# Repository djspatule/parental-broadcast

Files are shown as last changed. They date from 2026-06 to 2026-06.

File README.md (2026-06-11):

# parental-broadcast

A one-button Wi-Fi intercom for children's bedrooms, built on an **ESP32** +
**MAX98357A** I2S amplifier. Open a web page on your phone, tap a button, and a
pre-recorded voice message plays through the speaker in the kids' room — no app,
no cloud, no subscription.

```
Phone (same Wi-Fi)
      |
      | HTTP  →  http://interphone-enfants.local
      |
   ESP32
      |
      | I2S (BCLK / LRC / DIN)
      |
  MAX98357A  →  Speaker (4 Ω or 8 Ω, 1–3 W)
```

---

## Hardware

### Required

| Part | Notes |
| --- | --- |
| ESP32 DevKit (or equivalent) | Any classic ESP32 with 4 MB flash |
| MAX98357A I2S amplifier module | Adafruit breakout or clone |
| Speaker, 4 Ω or 8 Ω, 1–3 W | Small bookshelf or project speaker |
| Dupont wires | |
| USB cable + stable USB power supply | Dedicated supply preferred over a laptop port |

### Recommended but not required for V1

- Small enclosure
- Status LED (see [Improvements](#improvements))
- Physical mute button (see [Improvements](#improvements))

---

## Wiring

| MAX98357A pin | ESP32 pin |
| --- | --- |
| VIN | 5 V |
| GND | GND |
| BCLK | GPIO 26 |
| LRC | GPIO 25 |
| DIN | GPIO 22 |
| SD | 3.3 V or VIN (must not float — LOW = shutdown) |

| Speaker terminal | MAX98357A terminal |
| --- | --- |
| + | OUT+ |
| − | OUT− |

> **Do not connect headphones** to the MAX98357A output — it is a speaker
> amplifier, not a headphone driver.

---

## Software setup

### Prerequisites

- [VS Code](https://code.visualstudio.com/) +
  [PlatformIO extension](https://platformio.org/install/ide?install=vscode)
- [ffmpeg](https://ffmpeg.org/) (for audio conversion)

### 1. Clone the repo

```bash
git clone https://github.com/YOUR_USERNAME/parental-broadcast.git
cd parental-broadcast
```

### 2. Set your Wi-Fi credentials

Edit `src/main.cpp`, lines near the top:

```cpp
const char* WIFI_SSID = "YOUR_WIFI_SSID";
const char* WIFI_PASS = "YOUR_WIFI_PASSWORD";
```

> Never commit real credentials. The `.gitignore` does not protect `main.cpp` —
> keep a local-only copy if needed.

### 3. Prepare audio files

Record your own voice for each message (your voice works better with children
than a robot). Suggested messages:

| Filename | Suggested phrase |
| --- | --- |
| `moins_fort.wav` | "Les enfants, moins fort s'il vous plaît." |
| `retour_lit.wav` | "Retournez au lit maintenant." |
| `stop_courir.wav` | "Arrêtez de courir, vous allez réveiller tout le monde." |
| `separez_vous.wav` | "Séparez-vous tout de suite." |
| `tout_va_bien.wav` | "Tout va bien ?" |
| `papa_arrive.wav` | "Je vous entends, calmez-vous." |
| `dernier_avertissement.wav` | "Dernier avertissement, sinon je viens." |

Convert to the required format (mono, 16-bit PCM, 16 kHz) using the provided
script:

```bash
# Convert all *.m4a files in the current directory, output to data/
./scripts/convert_audio.sh

# Or convert a single file
./scripts/convert_audio.sh recording.m4a

# Manual ffmpeg command
ffmpeg -i input.m4a -ac 1 -ar 16000 -sample_fmt s16 data/moins_fort.wav
```

**Required WAV spec:**

| Parameter | Value |
| --- | --- |
| Container | WAV |
| Encoding | PCM (uncompressed) |
| Channels | Mono (1) |
| Bit depth | 16-bit |
| Sample rate | 16 000 Hz (or 22 050 Hz) |

Approximate sizes: 1 s ≈ 32 KB · 5 s ≈ 160 KB · 10 messages × 3 s ≈ 960 KB —
fits easily in 4 MB flash with a LittleFS partition.

### 4. Flash the firmware

Plug in the ESP32, then from VS Code PlatformIO terminal (or a terminal in the
project root):

```bash
# Compile and upload the firmware
pio run --target upload

# Upload the audio files to LittleFS
pio run --target uploadfs

# Open the serial monitor
pio device monitor
```

Expected serial output on boot:

```
Starting children's intercom...
Files in LittleFS:
  - /moins_fort.wav (48234 bytes)
  - /retour_lit.wav (51890 bytes)
  ...
Connected. IP: 192.168.1.42
mDNS active: http://interphone-enfants.local
HTTP server started.
```

---

## Usage

From your phone (connected to the same Wi-Fi):

```
http://interphone-enfants.local
```

If mDNS does not resolve (some Android versions), use the IP shown in the serial
monitor:

```
http://192.168.1.42
```

You can also trigger playback directly:

```
http://192.168.1.42/play?msg=moins_fort
```

**Tip:** on iPhone or Android, add the page to the home screen — it will appear
as a pseudo-app icon.

---

## Project structure

```
parental-broadcast/
├── platformio.ini          # PlatformIO build config
├── src/
│   └── main.cpp            # All ESP32 firmware
├── data/                   # WAV files go here (not committed)
│   └── .gitkeep
└── scripts/
    └── convert_audio.sh    # ffmpeg batch converter
```

---

## Configuration reference

All tuneable constants are at the top of `src/main.cpp`:

| Constant | Default | Description |
| --- | --- | --- |
| `WIFI_SSID` | `"YOUR_WIFI_SSID"` | Your Wi-Fi network name |
| `WIFI_PASS` | `"YOUR_WIFI_PASSWORD"` | Your Wi-Fi password |
| `MDNS_NAME` | `"interphone-enfants"` | mDNS hostname (`<name>.local`) |
| `I2S_BCLK`  | `26` | ESP32 GPIO for I2S bit clock |
| `I2S_LRC` | `25` | ESP32 GPIO for I2S word select |
| `I2S_DOUT`  | `22` | ESP32 GPIO for I2S data |
| `VOLUME` | `0.45` | Software volume, `0.0`–`1.0` |

---

## Fixing the IP address

mDNS is convenient, but a reserved IP in your router is more reliable for direct
access and troubleshooting. Look for "DHCP reservation" or "static lease" in
your router admin panel and assign a fixed IP to the ESP32's MAC address
(printed on the serial monitor at boot, or via `WiFi.macAddress()`).

---

## Improvements

These are out of scope for V1 but easy to add later:

### Status LED

```cpp
#define LED_PIN 2
digitalWrite(LED_PIN, isPlaying ? HIGH : LOW);
```

Suggested behaviour: solid = connected, blinking = playing, fast blink = Wi-Fi
error.

### Physical mute button

Wire a momentary button between GPIO 32 and GND, configure `INPUT_PULLUP`, and
set a `muted` flag that `playWav()` checks.

### Admin endpoints

- `GET /status` — already implemented, returns JSON
- `GET /reboot` — calls `ESP.restart()`
- `GET /volume?value=0.3` — updates `VOLUME` at runtime

### Attention chime

Play a short `ding.wav` before every message so children know to listen.

### Optional token authentication

If you ever expose the ESP32 beyond your local network (not recommended), add a
token to the URL:

```
/play?token=YOUR_SECRET&msg=moins_fort
```

In `handlePlay()`:

```cpp
const char* API_TOKEN = "change-me";

if (!server.hasArg("token") || server.arg("token") != API_TOKEN) {
  server.send(403, "text/plain", "Forbidden");
  return;
}
```

And include the token in the JavaScript `fetch()` call.

---

## Troubleshooting

| Symptom | Check |
| --- | --- |
| Page does not open via `.local` | Try the raw IP — mDNS is a best-effort protocol on some Android versions  |
| No sound | VIN→5 V, GND→GND, BCLK→26, LRC→25, DIN→22, SD→HIGH, speaker connected |
| Sound too fast or too slow | WAV is not 16 kHz — re-convert with `ffmpeg -ar 16000` |
| Sound is distorted / clipping | Lower `VOLUME` (e.g. `0.25`) |
| Message is cut off | A second button press while playing is silently ignored (by design) |
| File not found at runtime | Re-run `pio run --target uploadfs` and check the serial monitor file list |

---

## Security notes

- Do not expose this device to the internet (no port forwarding).
- The whitelist in `safeMessageToPath()` ensures arbitrary file paths cannot be
  requested via the URL.
- Keep the device on your home or IoT Wi-Fi network only.
- Keep the volume at a reasonable level.

---

## License

MIT — do whatever you want with it.

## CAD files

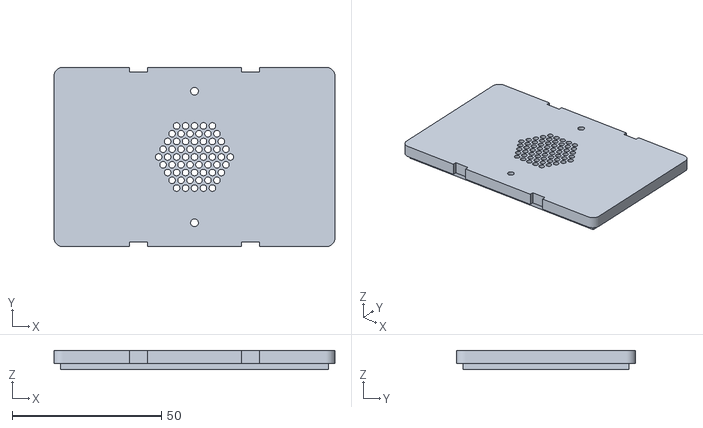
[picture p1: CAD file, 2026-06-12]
enclosure/interphone_lid.stl
94.0 x 60.0 x 6.50

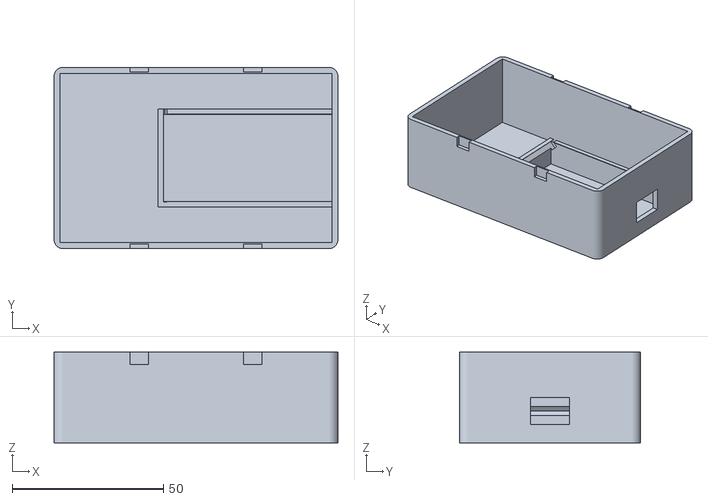
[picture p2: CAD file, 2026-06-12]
enclosure/interphone_body.stl
94.0 x 60.0 x 30.0

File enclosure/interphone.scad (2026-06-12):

// ============================================================
//  Children's Intercom — 3D-printable enclosure
//
//  Contents: ESP32 DevKit + MAX98357A + 31×31 mm top-firing
//            speaker (QUARKZMAN, JST-PH2.0, 2-ear, 44 mm span)
//
//  Two-part print — change PART then export each to STL:
//    PART = "body"   → the box (floor + walls + ESP32 cradle)
//    PART = "lid"    → the top plate with speaker grille
//    PART = "both"   → coloured preview in OpenSCAD viewer
//
//  Closure: 2 rubber bands running around the SHORT sides.
//  Notches on front + back long walls keep them from sliding up.
//
//  Hardware needed:
//    2 × M2.5×8 screws   (speaker ears → lid)
//    2 × rubber bands     (≈ 15–18 cm circumference)
// ============================================================

PART = "both"; // "body" | "lid" | "both"

// ── Shell ────────────────────────────────────────────────────
WALL  = 2.0;   // wall thickness everywhere
LID_T = 4.5;   // lid plate thickness
FIT   = 0.25;  // clearance between locating rim and body inner wall
LIP_H = 2.0;   // depth the locating rim descends into the body
LIP_W = 1.8;   // thickness of the hollow locating rim walls

// ── Internal cavity ─────────────────────────────────────────
// X = left–right (along ESP32 long axis, USB end toward right wall)
// Y = front–back
// Z = up (floor at z=WALL from outside bottom)
IN_W = 90;   // inner width  — 55 mm ESP32 + cradle wall + amp + wires
IN_D = 56;   // inner depth  — 28 mm ESP32 + clearance, centred
IN_H = 28;   // inner height — 8 mm under-PCB + PCB + headroom

// ── ESP32 cradle ─────────────────────────────────────────────
// U-channel (3 walls), open on the RIGHT (USB) end.
// The ESP32 drops in from above; the lid holds it down.
// USB cable exits straight through the right short wall.
//
// Measured ESP32 DevKit: 55 × 28 mm PCB, 8 mm of components below.
ESP_L   = 55;    // board length (X axis)
ESP_D   = 28;    // board width  (Y axis)
ESP_CLR =  0.4;  // clearance each side (total 0.8 mm — snug but insertable)
CRD_T   =  1.8;  // cradle wall thickness
CRD_H   = 10;    // cradle wall height (clips past PCB level at 8 mm)

// ── USB cable cutout (RIGHT short wall, x = OUT_W face) ──────
// ESP32 USB port sits at PCB height = WALL + 8 mm from box bottom.
// Hole is centred on that wall in Y, generous in Z.
USB_W   = 13;    // hole width  (micro-USB body ≈ 8 mm, cable ≈ 10 mm)
USB_H   =  9;    // hole height
USB_Z   =  6;    // bottom of hole from outside box bottom
                 // (PCB at 10 mm, USB connector ~1 mm below PCB top → 9 mm centre)

// ── Speaker (lid) ────────────────────────────────────────────
SPK_SPAN  = 44;   // ear screw hole span (Y axis), 2 holes
SPK_SCR_R =  1.3; // M2.5 self-tap radius in lid

GRL_R     = 13.0; // grille area radius
GRL_HOLE  =  1.1; // individual grille hole radius
GRL_PITCH =  3.0; // hex grid pitch

// ── Rubber-band notches (front + back long walls) ────────────
NOTCH_W = 6;    // notch width  (band sits in here)
NOTCH_H = 4;    // notch height from top of body wall downward
NOTCH_D = 1.5;  // notch depth  from outer surface inward

// ── Foot pads ────────────────────────────────────────────────
FOOT_R  = 4.0;
FOOT_H  = 0.8;
FOOT_IN = 7.0;

// ============================================================
//  Derived
// ============================================================
OUT_W  = IN_W + 2*WALL;   // outer width
OUT_D  = IN_D + 2*WALL;   // outer depth
BODY_H = IN_H + WALL;     // outer body height (floor + walls, open top)

$fn = 64;

LID_CX = OUT_W / 2;
LID_CY = OUT_D / 2;

// Cradle inner dimensions (with clearance)
CRD_IW = ESP_L + ESP_CLR * 2;  // inner length (X)
CRD_ID = ESP_D + ESP_CLR * 2;  // inner width  (Y)

// Cradle outer dimensions
CRD_OW = CRD_IW + CRD_T;       // +1 wall on closed (left) end only
CRD_OD = CRD_ID + CRD_T * 2;   // +1 wall each side (Y)

// Cradle position in box interior coordinates (before WALL offset)
// Right end of cradle flush with inner face of right wall
CRD_X = IN_W - CRD_OW;         // closed end x (inner coords)
CRD_Y = (IN_D - CRD_OD) / 2;   // centred in Y

// ============================================================
//  Helper — rounded rectangular prism
// ============================================================
module rbox(w, d, h, r = 3) {
    hull()
        for (x = [r, w-r], y = [r, d-r])
            translate([x, y, 0])
                cylinder(r=r, h=h);
}

// ============================================================
//  ESP32 CRADLE
//  Origin at the closed (left) end, floor level.
//  U-channel open toward +X (USB / right wall).
// ============================================================
module esp32_cradle() {
    // Lead-in chamfer height at top of walls for easier insertion
    CHAMFER = 1.5;

    difference() {
        // Outer block
        cube([CRD_OW, CRD_OD, CRD_H]);

        // Hollow centre (ESP32 slot), open on +X face
        translate([CRD_T, CRD_T, -0.1])
            cube([CRD_IW + 0.1, CRD_ID, CRD_H + 0.2]);

        // Chamfer the top inner edges of the two side walls for easy drop-in
        translate([CRD_T, CRD_T - 0.1, CRD_H - CHAMFER])
            rotate([-45, 0, 0])
                cube([CRD_IW, CHAMFER * 2, CHAMFER * 2]);
        translate([CRD_T, CRD_T + CRD_ID - CHAMFER + 0.1, CRD_H - CHAMFER])
            rotate([45, 0, 0])
                cube([CRD_IW, CHAMFER * 2, CHAMFER * 2]);

        // Chamfer the top inner edge of the closed end wall
        translate([CRD_T - CHAMFER, CRD_T - 0.1, CRD_H - CHAMFER])
            rotate([0, 45, 0])
                cube([CHAMFER * 2, CRD_OD + 0.2, CHAMFER * 2]);
    }
}

// ============================================================
//  BODY
// ============================================================
module body() {
    difference() {
        rbox(OUT_W, OUT_D, BODY_H);

        // Inner cavity (open top)
        translate([WALL, WALL, WALL])
            cube([IN_W, IN_D, IN_H + 1]);

        // USB hole — right short wall (x = OUT_W face), centred in Y
        translate([OUT_W - WALL - 0.1, OUT_D/2 - USB_W/2, USB_Z])
            cube([WALL + 0.2, USB_W, USB_H]);

        // Rubber-band notches — front long wall (y = 0 face)
        for (x = [OUT_W*0.3, OUT_W*0.7])
            translate([x - NOTCH_W/2, -0.1, BODY_H - NOTCH_H])
                cube([NOTCH_W, NOTCH_D + 0.1, NOTCH_H + 0.1]);

        // Rubber-band notches — back long wall (y = OUT_D face)
        for (x = [OUT_W*0.3, OUT_W*0.7])
            translate([x - NOTCH_W/2, OUT_D - NOTCH_D, BODY_H - NOTCH_H])
                cube([NOTCH_W, NOTCH_D + 0.1, NOTCH_H + 0.1]);
    }

    // ESP32 cradle — sits on interior floor, USB end toward right wall
    translate([WALL + CRD_X, WALL + CRD_Y, WALL])
        esp32_cradle();

    // Foot pads
    for (x = [FOOT_IN, OUT_W - FOOT_IN], y = [FOOT_IN, OUT_D - FOOT_IN])
        translate([x, y, 0])
            cylinder(r=FOOT_R, h=FOOT_H);
}

// ============================================================
//  LID  (print grille-face-up for cleanest holes)
// ============================================================
module lid() {
    RIM_OX = WALL + FIT;
    RIM_OY = WALL + FIT;
    RIM_OW = IN_W - 2*FIT;
    RIM_OD = IN_D - 2*FIT;
    RIM_IW = RIM_OW - 2*LIP_W;
    RIM_ID = RIM_OD - 2*LIP_W;

    difference() {
        union() {
            rbox(OUT_W, OUT_D, LID_T);

            // Locating rim — hollow square tube, hangs below plate
            translate([RIM_OX, RIM_OY, -LIP_H])
                difference() {
                    cube([RIM_OW, RIM_OD, LIP_H]);
                    translate([LIP_W, LIP_W, -0.1])
                        cube([RIM_IW, RIM_ID, LIP_H + 0.2]);
                }
        }

        // Speaker grille — hex grid, circular boundary, through full plate
        translate([LID_CX, LID_CY, -0.1])
            for (row = [-12:12], col = [-12:12]) {
                gx = col * GRL_PITCH + (abs(row) % 2) * GRL_PITCH / 2;
                gy = row * GRL_PITCH * 0.866;
                if (sqrt(gx*gx + gy*gy) < GRL_R)
                    translate([gx, gy, 0])
                        cylinder(r=GRL_HOLE, h=LID_T + 0.2);
            }

        // Speaker mounting holes — through plate AND rim where rim exists
        for (dy = [-1, 1])
            translate([LID_CX, LID_CY + dy * SPK_SPAN/2, -(LIP_H + 0.1)])
                cylinder(r=SPK_SCR_R, h=LID_T + LIP_H + 0.2);

        // Rubber-band notches on lid edges (same X positions as body notches)
        for (x = [OUT_W*0.3, OUT_W*0.7]) {
            translate([x - NOTCH_W/2, -0.1, -0.1])
                cube([NOTCH_W, NOTCH_D + 0.1, LID_T + 0.2]);
            translate([x - NOTCH_W/2, OUT_D - NOTCH_D, -0.1])
                cube([NOTCH_W, NOTCH_D + 0.1, LID_T + 0.2]);
        }
    }
}
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

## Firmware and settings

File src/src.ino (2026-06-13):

#include <Arduino.h>
#include <WiFi.h>
#include <WebServer.h>
#include <ESPmDNS.h>
#include <LittleFS.h>
#include "driver/i2s.h"
#include <time.h>
#include <math.h>

// Forward-declared here so arduino-cli prototype injection finds it before use
struct WavInfo {
  uint16_t audioFormat, numChannels, bitsPerSample;
  uint32_t sampleRate, dataStart, dataSize;
};

// =========================
// CONFIGURATION
// =========================

const char* WIFI_SSID = "YOUR_WIFI_SSID";
const char* WIFI_PASS = "YOUR_WIFI_PASSWORD";
const char* MDNS_NAME = "interphone-enfants";

#define I2S_PORT I2S_NUM_0
#define I2S_BCLK 26
#define I2S_LRC  25
#define I2S_DOUT 22

float VOLUME = 0.45;

// =========================
// GLOBALS
// =========================

WebServer server(80);
bool isPlaying = false;

#define LOG_FILE    "/playlog.txt"
#define LABELS_FILE "/labels.txt"

// Default labels — seeded into LABELS_FILE on first boot.
// Format: filename_stem=Display label[|css_class]
// css classes: (none)=blue, secondary=grey, warning=red
const char* DEFAULT_LABELS =
  "moins_fort=Moins fort\n"
  "retour_lit=Retour au lit\n"
  "stop_courir=Arrêtez de courir\n"
  "separez_vous=Séparez-vous\n"
  "tout_va_bien=Tout va bien|secondary\n"
  "papa_arrive=Parents arrivent mécontents|secondary\n"
  "dernier_avertissement=Dernier avertissement|warning\n";

// =========================
// LABELS (labels.txt)
// =========================

struct LabelEntry {
  String stem;   // filename without .wav
  String label;  // display text
  String cls;    // css class
};

static LabelEntry g_labels[32];
static int        g_labelCount = 0;

void loadLabels() {
  g_labelCount = 0;
  File f = LittleFS.open(LABELS_FILE, "r");
  if (!f) return;
  while (f.available() && g_labelCount < 32) {
    String line = f.readStringUntil('\n');
    line.trim();
    if (line.length() == 0) continue;
    int eq = line.indexOf('=');
    if (eq < 1) continue;
    String stem = line.substring(0, eq);
    String rest = line.substring(eq + 1);
    String lbl, cls;
    int pipe = rest.indexOf('|');
    if (pipe >= 0) { lbl = rest.substring(0, pipe); cls = rest.substring(pipe + 1); }
    else           { lbl = rest; cls = ""; }
    g_labels[g_labelCount++] = {stem, lbl, cls};
  }
  f.close();
}

void saveLabels() {
  File f = LittleFS.open(LABELS_FILE, "w");
  if (!f) return;
  for (int i = 0; i < g_labelCount; i++) {
    f.print(g_labels[i].stem + "=" + g_labels[i].label);
    if (g_labels[i].cls.length()) f.print("|" + g_labels[i].cls);
    f.print("\n");
  }
  f.close();
}

// Returns index of stem in g_labels, or -1
int findLabel(const String& stem) {
  for (int i = 0; i < g_labelCount; i++)
    if (g_labels[i].stem == stem) return i;
  return -1;
}

String getLabelFor(const String& stem) {
  int i = findLabel(stem);
  return i >= 0 ? g_labels[i].label : stem;
}

void addLabel(const String& stem, const String& label) {
  int i = findLabel(stem);
  if (i >= 0) { g_labels[i].label = label; }
  else if (g_labelCount < 32) { g_labels[g_labelCount++] = {stem, label, ""}; }
  saveLabels();
}

void removeLabel(const String& stem) {
  int i = findLabel(stem);
  if (i < 0) return;
  for (int j = i; j < g_labelCount - 1; j++) g_labels[j] = g_labels[j + 1];
  g_labelCount--;
  saveLabels();
}

// =========================
// LOG (playlog.txt)
// =========================
// Line format: "YYYY-MM-DD total stem1:n1,stem2:n2\n"

String getToday() {
  struct tm t;
  if (!getLocalTime(&t)) return "unknown";
  char buf[11];
  strftime(buf, sizeof(buf), "%Y-%m-%d", &t);
  return String(buf);
}

void incrementLog(const String& stem) {
  String today = getToday();
  if (today == "unknown") return;

  String content = "";
  File f = LittleFS.open(LOG_FILE, "r");
  if (f) { content = f.readString(); f.close(); }

  bool found = false;
  String output = "";
  int start = 0;

  while (start < (int)content.length()) {
    int nl = content.indexOf('\n', start);
    if (nl < 0) nl = content.length();
    String line = content.substring(start, nl);
    line.trim();
    start = nl + 1;
    if (line.length() == 0) continue;

    // Parse: date total detail
    int s1 = line.indexOf(' ');
    if (s1 < 0) { output += line + "\n"; continue; }
    String date = line.substring(0, s1);
    int s2 = line.indexOf(' ', s1 + 1);
    int total = 0;
    String detail = "";
    if (s2 < 0) { total = line.substring(s1 + 1).toInt(); }
    else        { total = line.substring(s1 + 1, s2).toInt(); detail = line.substring(s2 + 1); }

    if (date == today) {
      found = true;
      total++;
      // Update or add this stem in detail
      bool stemFound = false;
      String newDetail = "";
      int ds = 0;
      while (ds < (int)detail.length()) {
        int dc = detail.indexOf(',', ds);
        if (dc < 0) dc = detail.length();
        String pair = detail.substring(ds, dc);
        ds = dc + 1;
        if (pair.length() == 0) continue;
        int col = pair.indexOf(':');
        if (col < 0) { newDetail += (newDetail.length() ? "," : "") + pair; continue; }
        String pStem = pair.substring(0, col);
        int pCount   = pair.substring(col + 1).toInt();
        if (pStem == stem) { pCount++; stemFound = true; }
        newDetail += (newDetail.length() ? "," : "") + pStem + ":" + String(pCount);
      }
      if (!stemFound) newDetail += (newDetail.length() ? "," : "") + stem + ":1";
      output += date + " " + String(total) + " " + newDetail + "\n";
    } else {
      output += line + "\n";
    }
  }

  if (!found) output += today + " 1 " + stem + ":1\n";

  File fw = LittleFS.open(LOG_FILE, "w");
  if (fw) { fw.print(output); fw.close(); }
}

// =========================
// I2S SETUP
// =========================

void setupI2S(int sampleRate) {
  i2s_driver_uninstall(I2S_PORT);
  i2s_config_t cfg = {
    .mode = (i2s_mode_t)(I2S_MODE_MASTER | I2S_MODE_TX),
    .sample_rate = (uint32_t)sampleRate,
    .bits_per_sample = I2S_BITS_PER_SAMPLE_16BIT,
    .channel_format = I2S_CHANNEL_FMT_RIGHT_LEFT,
    .communication_format = I2S_COMM_FORMAT_STAND_I2S,
    .intr_alloc_flags = ESP_INTR_FLAG_LEVEL1,
    .dma_buf_count = 8,
    .dma_buf_len = 512,
    .use_apll = false,
    .tx_desc_auto_clear = true,
    .fixed_mclk = 0
  };
  i2s_pin_config_t pins = {
    .bck_io_num = I2S_BCLK,
    .ws_io_num  = I2S_LRC,
    .data_out_num = I2S_DOUT,
    .data_in_num  = I2S_PIN_NO_CHANGE
  };
  if (i2s_driver_install(I2S_PORT, &cfg, 0, NULL) != ESP_OK) return;
  i2s_set_pin(I2S_PORT, &pins);
  i2s_zero_dma_buffer(I2S_PORT);
}

// =========================
// CHIME (synthesised — no WAV file needed)
// =========================

void playChime() {
  const int SR = 16000;
  // Two tones: 880 Hz then 660 Hz, 180 ms each, with fade envelope
  float freqs[2] = {880.0f, 660.0f};
  const int TONE_SAMPLES = SR * 180 / 1000;   // 2880 samples per tone
  const int FADE         = SR * 30  / 1000;   // 30 ms fade in/out
  const int GAP          = SR * 40  / 1000;   // 40 ms silence between tones

  int16_t buf[128]; // stereo: 64 frames × 2 ch

  for (int t = 0; t < 2; t++) {
    float freq = freqs[t];
    int s = 0;
    while (s < TONE_SAMPLES) {
      int batch = min(64, TONE_SAMPLES - s);
      for (int i = 0; i < batch; i++) {
        int pos = s + i;
        float env = 1.0f;
        if (pos < FADE)                        env = (float)pos / FADE;
        else if (pos > TONE_SAMPLES - FADE)    env = (float)(TONE_SAMPLES - pos) / FADE;
        float v = sinf(2.0f * M_PI * freq * pos / SR) * env * VOLUME * 0.55f;
        int16_t sample = (int16_t)(v * 32767.0f);
        buf[i * 2]     = sample;
        buf[i * 2 + 1] = sample;
      }
      size_t written;
      i2s_write(I2S_PORT, buf, batch * 4, &written, portMAX_DELAY);
      s += batch;
    }
    // Gap
    memset(buf, 0, sizeof(buf));
    for (int g = 0; g < GAP; g += 64) {
      int batch = min(64, GAP - g);
      size_t written;
      i2s_write(I2S_PORT, buf, batch * 4, &written, portMAX_DELAY);
    }
  }
}

// =========================
// WAV PLAYER
// =========================

static bool readBytes(File& f, void* b, size_t n) { return f.read((uint8_t*)b, n) == n; }

static uint32_t readU32(File& f) {
  uint8_t b[4]; if (!readBytes(f, b, 4)) return 0;
  return b[0] | (b[1]<<8) | (b[2]<<16) | (b[3]<<24);
}
static uint16_t readU16(File& f) {
  uint8_t b[2]; if (!readBytes(f, b, 2)) return 0;
  return b[0] | (b[1]<<8);
}

bool parseWav(File& f, WavInfo& info) {
  char riff[4], wave[4];
  f.seek(0);
  if (!readBytes(f, riff, 4)) return false;
  readU32(f); // riff size
  if (!readBytes(f, wave, 4)) return false;
  if (strncmp(riff, "RIFF", 4) || strncmp(wave, "WAVE", 4)) return false;

  bool gotFmt = false, gotData = false;
  while (f.available()) {
    char id[4]; if (!readBytes(f, id, 4)) break;
    uint32_t sz = readU32(f);
    uint32_t pos = f.position();
    if (!strncmp(id, "fmt ", 4)) {
      info.audioFormat  = readU16(f);
      info.numChannels  = readU16(f);
      info.sampleRate   = readU32(f);
      readU32(f); readU16(f); // byteRate, blockAlign
      info.bitsPerSample = readU16(f);
      gotFmt = true;
    } else if (!strncmp(id, "data", 4)) {
      info.dataStart = pos;
      info.dataSize  = sz;
      gotData = true;
    }
    f.seek(pos + sz);
    if (gotFmt && gotData) break;
  }
  return gotFmt && gotData;
}

int16_t applyVolume(int16_t s) {
  int32_t v = (int32_t)(s * VOLUME);
  if (v >  32767) v =  32767;
  if (v < -32768) v = -32768;
  return (int16_t)v;
}

bool playWav(const char* path) {
  if (isPlaying) return false;
  isPlaying = true;

  File f = LittleFS.open(path, "r");
  if (!f) { Serial.printf("File not found: %s\n", path); isPlaying = false; return false; }

  WavInfo wav;
  if (!parseWav(f, wav) || wav.audioFormat != 1 || wav.bitsPerSample != 16) {
    Serial.println("Unsupported WAV format.");
    f.close(); isPlaying = false; return false;
  }

  Serial.printf("Playing: %s (%lu Hz, %u ch)\n", path, wav.sampleRate, wav.numChannels);
  setupI2S(wav.sampleRate);
  f.seek(wav.dataStart);

  uint8_t inBuf[512];
  int16_t outBuf[512];
  uint32_t remaining = wav.dataSize;

  while (remaining > 0) {
    size_t toRead = remaining > 512 ? 512 : remaining;
    size_t got    = f.read(inBuf, toRead);
    if (got == 0) break;
    remaining -= got;

    size_t written;
    if (wav.numChannels == 1) {
      size_t samples = got / 2, out = 0;
      for (size_t i = 0; i < samples; i++) {
        int16_t s = applyVolume(((int16_t*)inBuf)[i]);
        outBuf[out++] = s; outBuf[out++] = s;
        if (out >= 512) { i2s_write(I2S_PORT, outBuf, out*2, &written, portMAX_DELAY); out = 0; }
      }
      if (out) i2s_write(I2S_PORT, outBuf, out*2, &written, portMAX_DELAY);
    } else {
      int16_t* s16 = (int16_t*)inBuf;
      for (size_t i = 0; i < got/2; i++) s16[i] = applyVolume(s16[i]);
      i2s_write(I2S_PORT, inBuf, got, &written, portMAX_DELAY);
    }
    yield();
  }

  i2s_zero_dma_buffer(I2S_PORT);
  f.close();
  isPlaying = false;
  return true;
}

// =========================
// SECURITY
// =========================

bool isSafeStem(const String& stem) {
  if (stem.length() == 0 || stem.length() > 40) return false;
  for (int i = 0; i < (int)stem.length(); i++) {
    char c = stem[i];
    if (!isalnum(c) && c != '_' && c != '-') return false;
  }
  return true;
}

// =========================
// HTML — MAIN PAGE (dynamic)
// =========================

String htmlPage() {
  String html = F("<!doctype html><html lang='fr'><head>"
    "<meta charset='utf-8'><title>Interphone enfants</title>"
    "<meta name='viewport' content='width=device-width,initial-scale=1'><link rel='icon' href='/favicon.ico'>"
    "<style>"
    ":root{font-family:system-ui,-apple-system,sans-serif}"
    "body{margin:0;background:#111;color:#f5f5f5}"
    "main{max-width:520px;margin:0 auto;padding:20px}"
    "h1{font-size:1.8rem;margin-bottom:.3rem}"
    "p{color:#bbb;margin-top:0;margin-bottom:1.5rem}"
    "button{width:100%;border:0;border-radius:14px;padding:18px 16px;margin:8px 0;"
           "font-size:1.2rem;font-weight:650;background:#2f80ed;color:#fff;"
           "box-shadow:0 4px 12px rgba(0,0,0,.25);cursor:pointer}"
    "button:active{transform:scale(.98);background:#1c65c9}"
    ".secondary{background:#444}"
    ".warning{background:#b84040}"
    ".volume-row{display:flex;align-items:center;gap:12px;margin:20px 0 8px}"
    ".volume-row label{white-space:nowrap;color:#bbb;font-size:.95rem;min-width:90px}"
    "input[type=range]{flex:1;accent-color:#2f80ed}"
    "#vol-val{color:#f5f5f5;min-width:36px;text-align:right;font-size:.95rem}"
    "#status{margin-top:16px;padding:12px;background:#222;border-radius:10px;color:#ddd;min-height:1.2rem}"
    ".footer-links{display:flex;gap:20px;justify-content:center;margin-top:20px}"
    ".footer-links a{color:#888;font-size:.9rem;text-decoration:none}"
    ".footer-links a:hover{color:#bbb}"
    "</style></head><body><main>"
    "<h1>Chambre enfants</h1>"
    "<p>Appuie sur un bouton pour diffuser un message.</p>");

  for (int i = 0; i < g_labelCount; i++) {
    String path = "/" + g_labels[i].stem + ".wav";
    if (!LittleFS.exists(path)) continue;
    String cls = g_labels[i].cls.length() ? " class='" + g_labels[i].cls + "'" : "";
    html += "<button" + cls + " onclick=\"play('" + g_labels[i].stem + "')\">"
          + g_labels[i].label + "</button>\n";
  }

  html += F("<div class='volume-row'>"
    "<label for='vol'>Volume&nbsp;:</label>"
    "<input type='range' id='vol' min='0' max='3' step='0.05' value='0.45'"
    " oninput='updateVolDisplay(this.value)' onchange='setVolume(this.value)'>"
    "<span id='vol-val'>0.45</span></div>"
    "<div id='status'>Prêt.</div>"
    "<div class='footer-links'>"
    "<a href='/log'>📋 Journal</a>"
    "<a href='/manage'>⚙️ Gérer les messages</a>"
    "</div>"
    "</main><script>"
    "async function play(msg){"
      "const s=document.getElementById('status');"
      "s.textContent='Envoi : '+msg+'...';"
      "try{"
        "const r=await fetch('/play?msg='+encodeURIComponent(msg));"
        "s.textContent=r.ok?'Message envoyé.':'Erreur : '+(await r.text());"
      "}catch(e){s.textContent='Impossible de joindre l\\'ESP32.';}"
    "}"
    "function updateVolDisplay(v){document.getElementById('vol-val').textContent=parseFloat(v).toFixed(2);}"
    "async function setVolume(v){updateVolDisplay(v);await fetch('/volume?value='+v);}"
    "fetch('/status').then(r=>r.json()).then(d=>{"
      "if(d.volume!==undefined){document.getElementById('vol').value=d.volume;updateVolDisplay(d.volume);}"
    "}).catch(()=>{});"
    "</script></body></html>");

  return html;
}

// =========================
// HTML — LOG PAGE
// =========================

String htmlLog() {
  String html = F("<!doctype html><html lang='fr'><head>"
    "<meta charset='utf-8'><title>Journal</title>"
    "<meta name='viewport' content='width=device-width,initial-scale=1'><link rel='icon' href='/favicon.ico'>"
    "<style>"
    "body{font-family:system-ui,sans-serif;background:#111;color:#f5f5f5;margin:0;padding:20px}"
    "h1{font-size:1.5rem}a{color:#2f80ed}"
    "table{border-collapse:collapse;width:100%;max-width:600px;margin-top:16px}"
    "th,td{padding:10px 14px;text-align:left;border-bottom:1px solid #333;vertical-align:top}"
    "th{color:#bbb;font-weight:500}"
    ".total{font-weight:bold;white-space:nowrap}"
    ".detail{color:#bbb;font-size:.9rem;line-height:1.6}"
    "</style></head><body>"
    "<h1>Journal des messages</h1>"
    "<p><a href='/'>← Retour</a></p>");

  File f = LittleFS.open(LOG_FILE, "r");
  if (!f || f.size() == 0) {
    html += "<p style='color:#bbb'>Aucun message envoyé pour l'instant.</p>";
    if (f) f.close();
    html += "</body></html>";
    return html;
  }

  // Collect lines
  String lines[64]; int count = 0;
  while (f.available() && count < 64) {
    String line = f.readStringUntil('\n'); line.trim();
    if (line.length()) lines[count++] = line;
  }
  f.close();

  html += "<table><tr><th>Date</th><th>Total</th><th>Détail</th></tr>";
  for (int i = count - 1; i >= 0; i--) {
    int s1 = lines[i].indexOf(' ');
    if (s1 < 0) continue;
    int s2 = lines[i].indexOf(' ', s1 + 1);
    String date   = lines[i].substring(0, s1);
    String total  = s2 < 0 ? lines[i].substring(s1 + 1) : lines[i].substring(s1 + 1, s2);
    String detail = s2 < 0 ? "" : lines[i].substring(s2 + 1);

    // Build friendly detail string
    String friendlyDetail = "";
    int ds = 0;
    while (ds < (int)detail.length()) {
      int dc = detail.indexOf(',', ds);
      if (dc < 0) dc = detail.length();
      String pair = detail.substring(ds, dc); ds = dc + 1;
      int col = pair.indexOf(':');
      if (col < 0) continue;
      String stem = pair.substring(0, col);
      String cnt  = pair.substring(col + 1);
      if (friendlyDetail.length()) friendlyDetail += "<br>";
      friendlyDetail += getLabelFor(stem) + " &times;" + cnt;
    }

    html += "<tr><td>" + date + "</td><td class='total'>" + total
          + "</td><td class='detail'>" + (friendlyDetail.length() ? friendlyDetail : "-")
          + "</td></tr>";
  }
  html += "</table></body></html>";
  return html;
}

// =========================
// HTML — MANAGE PAGE
// =========================

String htmlManage() {
  size_t used  = LittleFS.usedBytes();
  size_t total = LittleFS.totalBytes();
  size_t free  = total - used;

  String html = F("<!doctype html><html lang='fr'><head>"
    "<meta charset='utf-8'><title>Gérer les messages</title>"
    "<meta name='viewport' content='width=device-width,initial-scale=1'><link rel='icon' href='/favicon.ico'>"
    "<style>"
    "body{font-family:system-ui,sans-serif;background:#111;color:#f5f5f5;margin:0;padding:20px}"
    "h1,h2{font-size:1.3rem}a{color:#2f80ed}"
    "table{border-collapse:collapse;width:100%;max-width:520px;margin:12px 0}"
    "th,td{padding:9px 12px;text-align:left;border-bottom:1px solid #333}"
    "th{color:#bbb;font-weight:500}"
    ".del{color:#e05;font-size:.85rem;text-decoration:none}"
    ".del:hover{text-decoration:underline}"
    "form{max-width:520px;margin-top:20px}"
    "label{display:block;color:#bbb;font-size:.9rem;margin:12px 0 4px}"
    "input[type=text],input[type=file]{width:100%;box-sizing:border-box;"
      "background:#222;border:1px solid #444;border-radius:8px;"
      "padding:10px;color:#f5f5f5;font-size:1rem}"
    "button[type=submit]{margin-top:14px;padding:12px 24px;background:#2f80ed;"
      "color:#fff;border:0;border-radius:10px;font-size:1rem;cursor:pointer}"
    ".space{color:#888;font-size:.85rem;margin-bottom:4px}"
    ".warn{color:#e88}"
    "</style></head><body>"
    "<h1>⚙️ Gérer les messages</h1>"
    "<p><a href='/'>← Retour</a></p>");

  // Space indicator
  html += "<p class='space'>Espace utilisé : " + String(used / 1024) + " Ko / "
        + String(total / 1024) + " Ko — libre : " + String(free / 1024) + " Ko</p>";
  if (free < 50000)
    html += "<p class='warn'>⚠️ Moins de 50 Ko libres — supprimez des messages avant d'en ajouter.</p>";

  // Current messages table
  html += "<h2>Messages actuels</h2>"
          "<table><tr><th>Bouton</th><th>Fichier</th><th></th></tr>";
  for (int i = 0; i < g_labelCount; i++) {
    String path = "/" + g_labels[i].stem + ".wav";
    if (!LittleFS.exists(path)) continue;
    File wf = LittleFS.open(path, "r");
    String size = wf ? String(wf.size() / 1024) + " Ko" : "?";
    if (wf) wf.close();
    html += "<tr><td>" + g_labels[i].label + "</td><td>" + g_labels[i].stem
          + ".wav (" + size + ")</td>"
          + "<td><a class='del' href='/delete?file=" + g_labels[i].stem
          + "' onclick=\"return confirm('Supprimer " + g_labels[i].label + " ?')\">Supprimer</a></td></tr>";
  }
  html += "</table>";

  // Upload form
  html += F("<h2>Ajouter un message</h2>"
    "<form action='/upload' method='POST' enctype='multipart/form-data'>"
    "<label>Nom du bouton</label>"
    "<input type='text' name='label' placeholder='Ex : Dîner prêt' required maxlength='40'>"
    "<label>Fichier WAV <span style='color:#888'>(mono, 16 bits, 16 000 Hz)</span></label>"
    "<input type='file' name='file' accept='.wav' required>"
    "<button type='submit'>Envoyer</button>"
    "</form>"
    "<hr style='border-color:#333;margin:28px 0'>"
    "<h2>Système</h2>"
    "<a href='/reboot' onclick=\"return confirm('Redémarrer l\\'ESP32 ?')\" "
    "style='display:inline-block;padding:10px 20px;background:#555;color:#fff;"
    "border-radius:8px;text-decoration:none;font-size:.95rem'>🔄 Redémarrer l'ESP32</a>"
    "</body></html>");

  return html;
}

// =========================
// HTTP HANDLERS
// =========================

void handleRoot() {
  server.send(200, "text/html; charset=utf-8", htmlPage());
}

void handlePlay() {
  if (!server.hasArg("msg")) {
    server.send(400, "text/plain", "Missing: msg"); return;
  }
  String stem = server.arg("msg");
  if (!isSafeStem(stem)) {
    server.send(400, "text/plain", "Invalid message name"); return;
  }
  String path = "/" + stem + ".wav";
  if (!LittleFS.exists(path)) {
    server.send(404, "text/plain", "Audio file missing: " + path); return;
  }
  server.send(200, "text/plain", "Playing: " + stem);
  delay(20);
  incrementLog(stem);
  setupI2S(16000);
  playChime();
  playWav(path.c_str());
}

void handleStatus() {
  server.send(200, "application/json",
    "{\"wifi\":true,\"ip\":\"" + WiFi.localIP().toString() + "\","
    "\"playing\":" + String(isPlaying ? "true" : "false") + ","
    "\"volume\":" + String(VOLUME, 2) + "}");
}
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
void loop() {
  server.handleClient();
}

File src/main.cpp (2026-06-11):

#include <Arduino.h>
#include <WiFi.h>
#include <WebServer.h>
#include <ESPmDNS.h>
#include <LittleFS.h>
#include "driver/i2s.h"

// =========================
// WIFI CONFIGURATION
// =========================

const char* WIFI_SSID = "YOUR_WIFI_SSID";
const char* WIFI_PASS = "YOUR_WIFI_PASSWORD";

const char* MDNS_NAME = "interphone-enfants";

// =========================
// I2S CONFIGURATION
// =========================

#define I2S_PORT I2S_NUM_0

#define I2S_BCLK 26
#define I2S_LRC  25
#define I2S_DOUT 22

// Software volume: 0.0 to 1.0
// Start low, especially if the speaker is close to the bed.
float VOLUME = 0.45;

// =========================
// WEB SERVER
// =========================

WebServer server(80);

bool isPlaying = false;

// =========================
// HTML PAGE
// =========================

String htmlPage() {
  return R"rawliteral(
<!doctype html>
<html lang="fr">
<head>
  <meta charset="utf-8">
  <title>Interphone enfants</title>
  <meta name="viewport" content="width=device-width, initial-scale=1">
  <style>
    :root {
      font-family: system-ui, -apple-system, BlinkMacSystemFont, "Segoe UI", sans-serif;
    }
    body {
      margin: 0;
      background: #111;
      color: #f5f5f5;
    }
    main {
      max-width: 520px;
      margin: 0 auto;
      padding: 20px;
    }
    h1 {
      font-size: 1.8rem;
      margin-bottom: 0.3rem;
    }
    p {
      color: #bbb;
      margin-top: 0;
      margin-bottom: 1.5rem;
    }
    button {
      width: 100%;
      border: 0;
      border-radius: 14px;
      padding: 18px 16px;
      margin: 8px 0;
      font-size: 1.2rem;
      font-weight: 650;
      background: #2f80ed;
      color: white;
      box-shadow: 0 4px 12px rgba(0,0,0,0.25);
      cursor: pointer;
    }
    button:active {
      transform: scale(0.98);
      background: #1c65c9;
    }
    .secondary {
      background: #444;
    }
    .warning {
      background: #b84040;
    }
    #status {
      margin-top: 16px;
      padding: 12px;
      background: #222;
      border-radius: 10px;
      color: #ddd;
      min-height: 1.2rem;
    }
  </style>
</head>
<body>
  <main>
    <h1>Chambre enfants</h1>
    <p>Appuie sur un bouton pour diffuser un message.</p>

    <button onclick="play('moins_fort')">Moins fort</button>
    <button onclick="play('retour_lit')">Retour au lit</button>
    <button onclick="play('stop_courir')">Arrêtez de courir</button>
    <button onclick="play('separez_vous')">Séparez-vous</button>
    <button onclick="play('tout_va_bien')" class="secondary">Tout va bien ?</button>
    <button onclick="play('papa_arrive')" class="secondary">Papa arrive</button>
    <button onclick="play('dernier_avertissement')" class="warning">Dernier avertissement</button>

    <div id="status">Prêt.</div>
  </main>

  <script>
    async function play(msg) {
      const status = document.getElementById('status');
      status.textContent = "Sending: " + msg + "...";

      try {
        const res = await fetch('/play?msg=' + encodeURIComponent(msg));
        const text = await res.text();

        if (res.ok) {
          status.textContent = "Message sent.";
        } else {
          status.textContent = "Error: " + text;
        }
      } catch (e) {
        status.textContent = "Cannot reach ESP32.";
      }
    }
  </script>
</body>
</html>
)rawliteral";
}

// =========================
// I2S SETUP
// =========================

void setupI2S(int sampleRate) {
  i2s_driver_uninstall(I2S_PORT);

  i2s_config_t i2s_config = {
    .mode = (i2s_mode_t)(I2S_MODE_MASTER | I2S_MODE_TX),
    .sample_rate = (uint32_t)sampleRate,
    .bits_per_sample = I2S_BITS_PER_SAMPLE_16BIT,
    .channel_format = I2S_CHANNEL_FMT_RIGHT_LEFT,
    .communication_format = I2S_COMM_FORMAT_STAND_I2S,
    .intr_alloc_flags = ESP_INTR_FLAG_LEVEL1,
    .dma_buf_count = 8,
    .dma_buf_len = 512,
    .use_apll = false,
    .tx_desc_auto_clear = true,
    .fixed_mclk = 0
  };

  i2s_pin_config_t pin_config = {
    .bck_io_num = I2S_BCLK,
    .ws_io_num = I2S_LRC,
    .data_out_num = I2S_DOUT,
    .data_in_num = I2S_PIN_NO_CHANGE
  };

  esp_err_t err;

  err = i2s_driver_install(I2S_PORT, &i2s_config, 0, NULL);
  if (err != ESP_OK) {
    Serial.printf("i2s_driver_install error: %d\n", err);
    return;
  }

  err = i2s_set_pin(I2S_PORT, &pin_config);
  if (err != ESP_OK) {
    Serial.printf("i2s_set_pin error: %d\n", err);
    return;
  }

  i2s_zero_dma_buffer(I2S_PORT);
}

// =========================
// SIMPLE WAV READER
// =========================

struct WavInfo {
  uint16_t audioFormat;
  uint16_t numChannels;
  uint32_t sampleRate;
  uint16_t bitsPerSample;
  uint32_t dataStart;
  uint32_t dataSize;
};

bool readBytes(File& file, void* buffer, size_t len) {
  return file.read((uint8_t*)buffer, len) == len;
}

uint32_t readU32(File& file) {
  uint8_t b[4];
  if (!readBytes(file, b, 4)) return 0;
  return ((uint32_t)b[0]) |
         ((uint32_t)b[1] << 8) |
         ((uint32_t)b[2] << 16) |
         ((uint32_t)b[3] << 24);
}

uint16_t readU16(File& file) {
  uint8_t b[2];
  if (!readBytes(file, b, 2)) return 0;
  return ((uint16_t)b[0]) | ((uint16_t)b[1] << 8);
}

bool parseWav(File& file, WavInfo& info) {
  char riff[4];
  char wave[4];

  file.seek(0);

  if (!readBytes(file, riff, 4)) return false;
  uint32_t riffSize = readU32(file);
  (void)riffSize;
  if (!readBytes(file, wave, 4)) return false;

  if (strncmp(riff, "RIFF", 4) != 0 || strncmp(wave, "WAVE", 4) != 0) {
    return false;
  }

  bool foundFmt = false;
  bool foundData = false;

  while (file.available()) {
    char chunkId[4];
    if (!readBytes(file, chunkId, 4)) break;

    uint32_t chunkSize = readU32(file);
    uint32_t chunkDataStart = file.position();

    if (strncmp(chunkId, "fmt ", 4) == 0) {
      info.audioFormat  = readU16(file);
      info.numChannels  = readU16(file);
      info.sampleRate   = readU32(file);

      uint32_t byteRate   = readU32(file);
      uint16_t blockAlign = readU16(file);
      info.bitsPerSample  = readU16(file);

      (void)byteRate;
      (void)blockAlign;

      foundFmt = true;
    } else if (strncmp(chunkId, "data", 4) == 0) {
      info.dataStart = chunkDataStart;
      info.dataSize  = chunkSize;
      foundData = true;
    }

    file.seek(chunkDataStart + chunkSize);

    if (foundFmt && foundData) break;
  }

  return foundFmt && foundData;
}

int16_t applyVolume(int16_t sample) {
  int32_t scaled = (int32_t)(sample * VOLUME);
  if (scaled >  32767) scaled =  32767;
  if (scaled < -32768) scaled = -32768;
  return (int16_t)scaled;
}
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

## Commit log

2026-06-11 Initial commit: ESP32 children's room intercom
    PlatformIO project targeting ESP32 + MAX98357A I2S amplifier.
    Serves a mobile-friendly web UI over mDNS, plays pre-recorded
    WAV messages from LittleFS via I2S. Includes audio conversion
    script and full wiring/setup documentation.
2026-06-12 Add Makefile, ESP32 cradle enclosure (SCAD+STL), rename .cpp→.ino
    [interphone.scad, interphone_body.stl, interphone_lid.stl]
2026-06-13 Add volume endpoint, daily play log, NTP sync, UI improvements
    - /volume?value=X endpoint (0.0–3.0, allows soft clipping above 1.0)
    - Volume slider on web page; syncs with current value on load
    - /log endpoint: HTML table of messages sent per day
    - NTP time sync on boot (France timezone, DST-aware)
    - Rename buttons: "Papa arrive" → "Parents arrivent mécontents",
    "Tout va bien ?" → "Tout va bien"
    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
2026-06-13 Add chime, per-message log, and custom message upload
    - Synthesised two-tone chime plays before every message (no WAV file needed)
    - Daily log now tracks which message was sent and how many times,
    displayed as a friendly table at /log
    - /manage page: upload new WAV messages from the browser, delete existing ones,
    shows LittleFS space usage
    - Main page now reads messages dynamically from labels.txt (uploaded messages
    appear automatically as new buttons)
    - Security: filename sanitisation replaces hardcoded whitelist
    [src.ino]
2026-06-13 Persist volume across reboots, add reboot button to /manage
    - Volume saved to /volume.txt on every change, restored on boot
    - /reboot endpoint calls ESP.restart() with confirmation dialog
    [src.ino]
